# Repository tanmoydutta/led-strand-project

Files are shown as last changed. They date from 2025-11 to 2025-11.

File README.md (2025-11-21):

# Autonoe
An RGB and Neopixel LED controller board powered by ESP32-C3



The module has option for unified 5V supply for LEDs and the MCU LDO and can provide support for higher voltages via the dedicated barrel jack socket. Separate 5V power then can be supplied via the USB-C connector -


A small solder bridge unifies the circuit power for 5V power operations and for higher current feed via the barrel jack socket-


Dual LED interface for RGB and Addressable LEDs - 


This is an OSHWA certified hardware - 
<p align="center">
  <a href="https://certification.oshwa.org/nl000036.html">
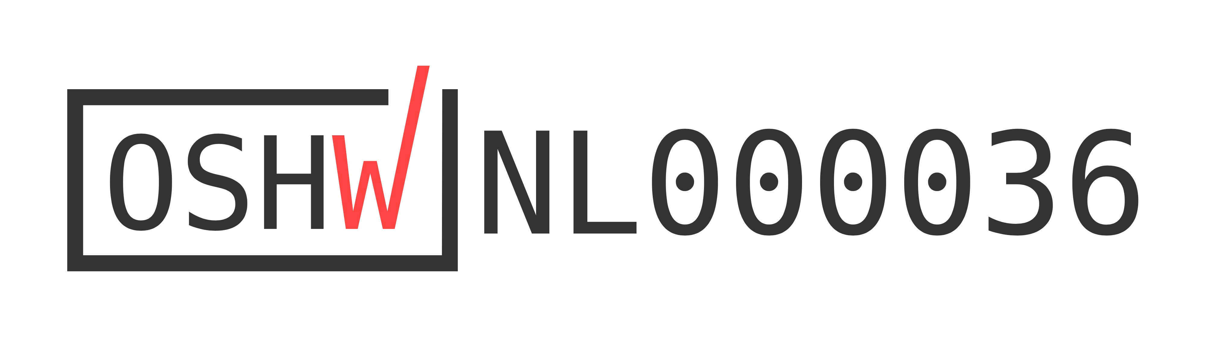
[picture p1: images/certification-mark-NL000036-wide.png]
OSHWA OSHWA Certification
    
  </a>
</p>



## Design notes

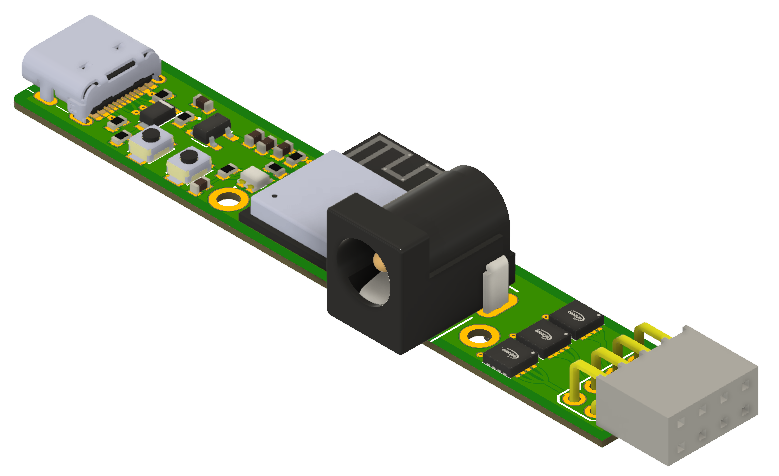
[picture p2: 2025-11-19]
images/AutonoeGingerBread3.png

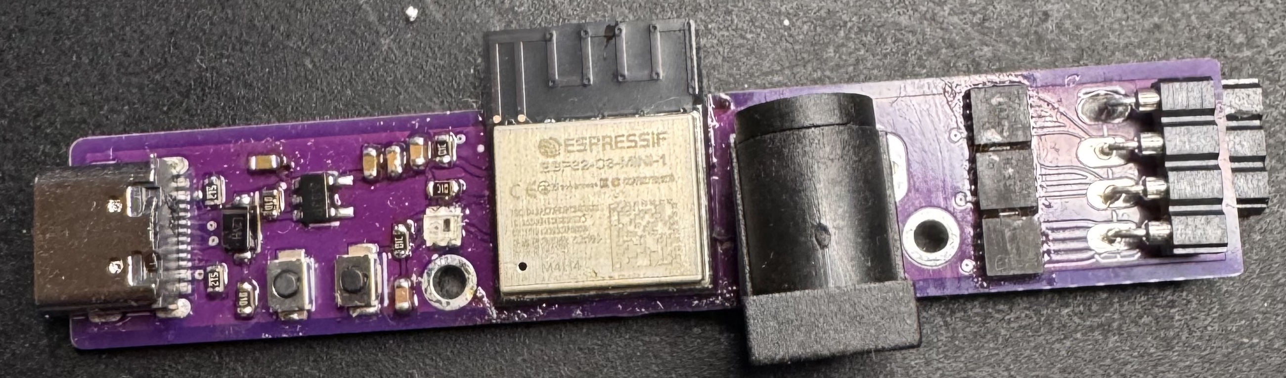
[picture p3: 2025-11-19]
images/module.jpg

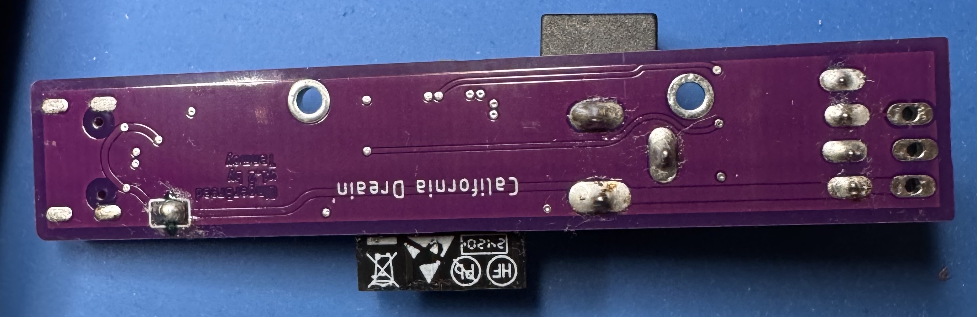
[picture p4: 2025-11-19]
images/module_back.jpg

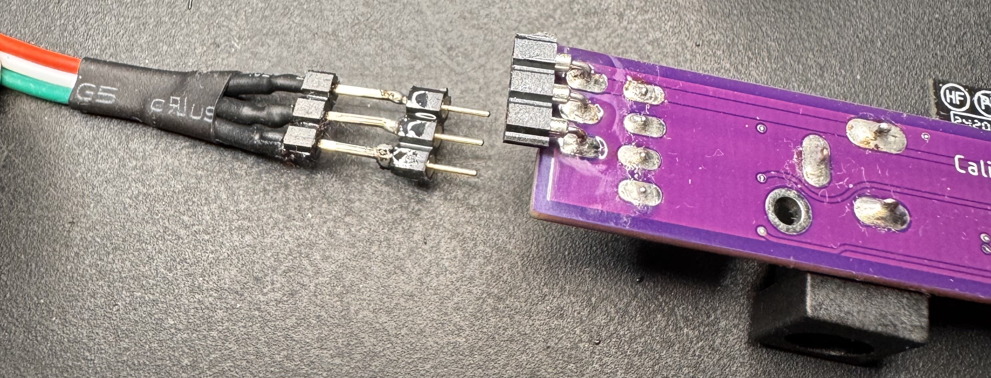
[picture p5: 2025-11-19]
images/addressable.jpg

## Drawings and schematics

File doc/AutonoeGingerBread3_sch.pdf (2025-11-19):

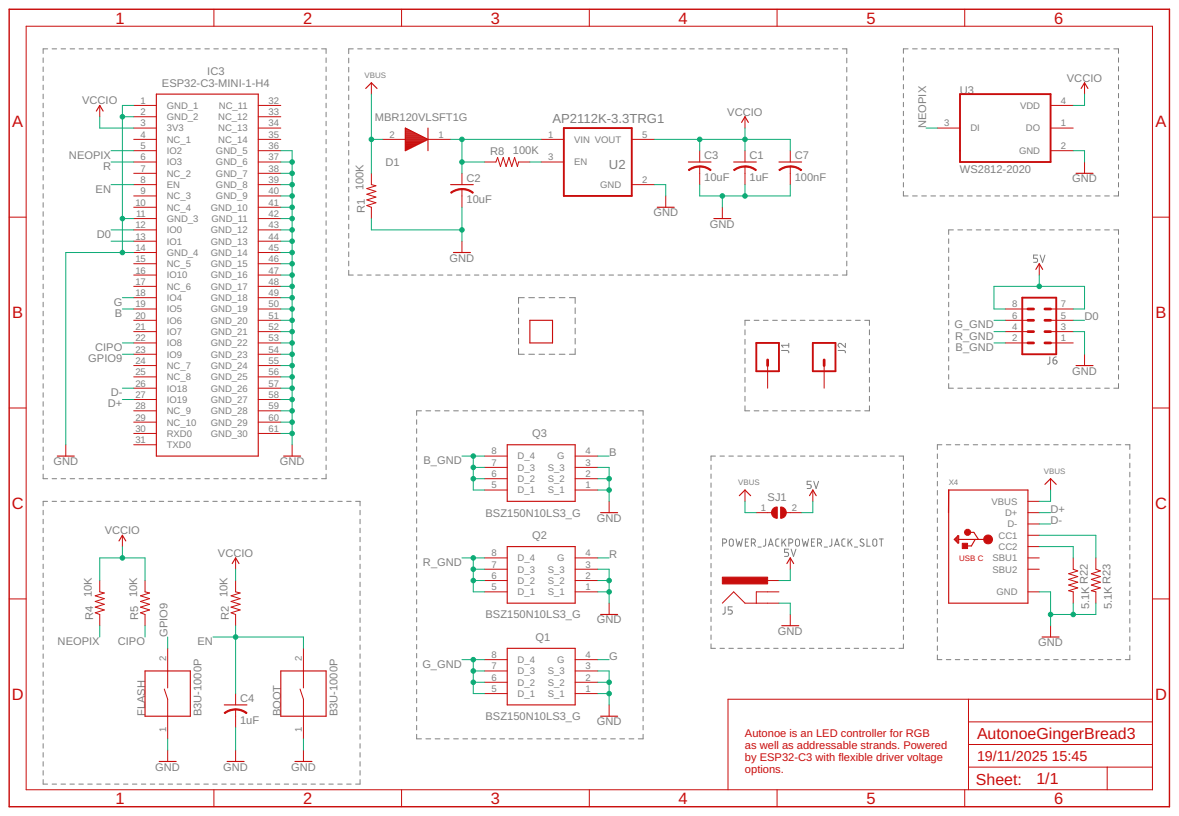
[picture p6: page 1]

44 GND_14 | GND

15 17 18 | | 46 GND_16

Autonoe is an LED controller for RGB as well as addressable strands. Powered by ESP32-C3 with flexible driver voltage options.

Sheet: 1/1

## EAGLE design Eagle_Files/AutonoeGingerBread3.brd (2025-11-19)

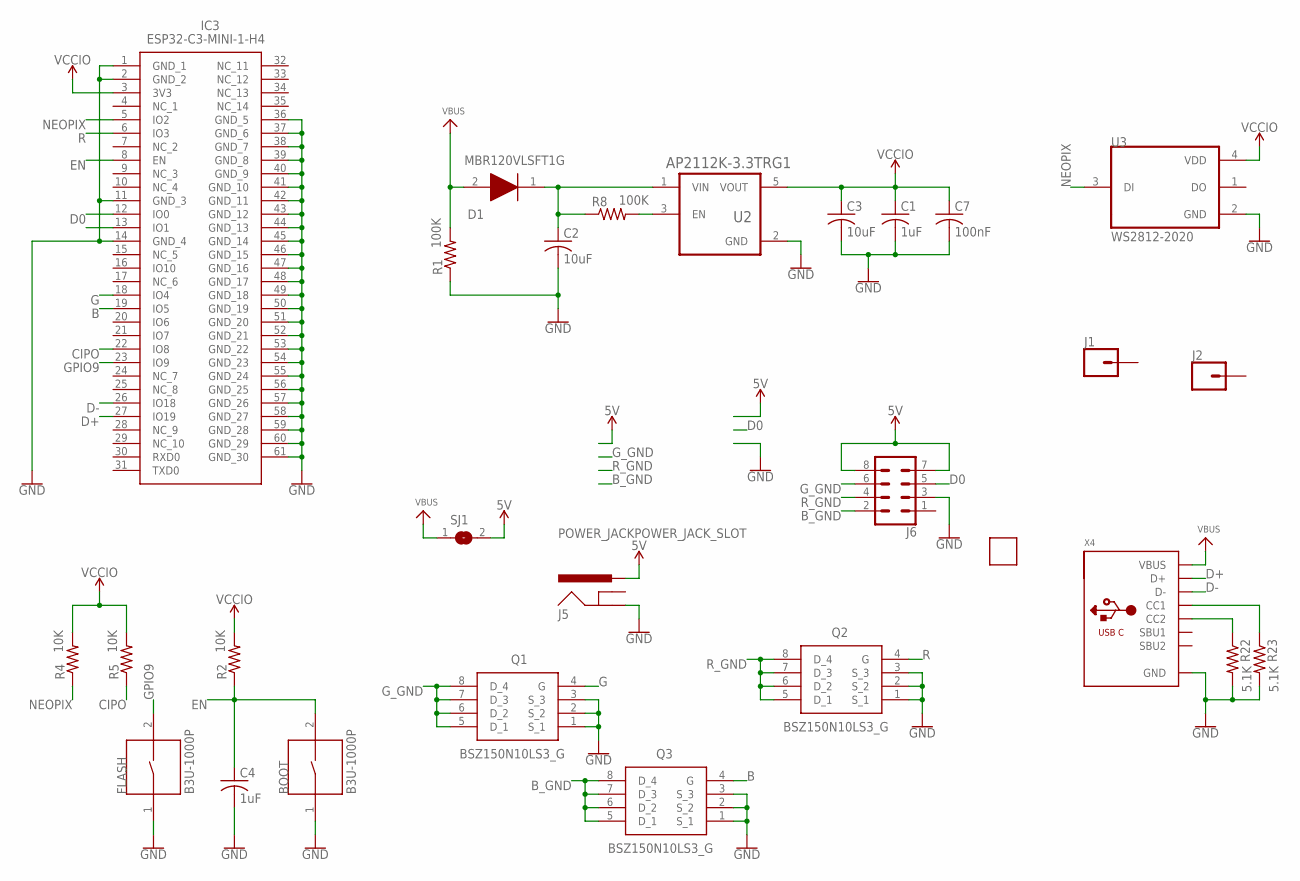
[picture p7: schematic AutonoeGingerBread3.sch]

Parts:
BOOT: B3U-1000P; SW_B3U-1000P
C1, C4: 1uF; C0402
C2, C3: 10uF; C0402
C7: 100nF; C0402
D1: MBR120VLSFT1G; SODFL3616X98N
FLASH: B3U-1000P; SW_B3U-1000P
IC3: ESP32-C3-MINI-1-H4; ESP32C3MINI1H4
J1, J2: CONN_01PTH_2MM; 1X01_2MM
J5: POWER_JACKPOWER_JACK_SLOT; POWER_JACK_PTH_SLOT
J6: CONN_04X2; 2X4
Q1, Q2, Q3: BSZ150N10LS3_G; BSZ180P03NS3EGATMA1
R1, R8: 100K; R0402
R2, R4, R5: 10K; R0402
R22, R23: 5.1K; R0402
SJ1: SJ
U2: AP2112K-3.3TRG1; SOT95P285X140-5N
U3: WS2812-2020; LED_WS2812-2020
U$3: SMARTT_SMALL
X4: MICROBUILDER_USB_C; MICROBUILDER_USB_C_CUSB31-CFM2AX-01-X

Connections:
5V: J5.PWR, J6.7, J6.8, SJ1.2
B: IC3.19 (IO5), Q3.4 (G)
B_GND: J6.2, Q3.5 (D_1), Q3.6 (D_2), Q3.7 (D_3), Q3.8 (D_4)
CIPO: IC3.22 (IO8), R5.1
D0: IC3.12 (IO0), J6.5
D+: IC3.27 (IO19), X4.A6 (D+), X4.B6 (D+)
D-: IC3.26 (IO18), X4.A7 (D-), X4.B7 (D-)
EN: BOOT.2, C4.1, IC3.8 (EN), R2.1
G: IC3.18 (IO4), Q1.4 (G)
GND: BOOT.1, C1.2, C2.2, C3.2, C4.2, C7.2, FLASH.1, IC3.1 (GND_1), IC3.2 (GND_2), IC3.11 (GND_3), IC3.14 (GND_4), IC3.36 (GND_5), IC3.37 (GND_6), IC3.38 (GND_7), IC3.39 (GND_8), IC3.40 (GND_9), IC3.41 (GND_10), IC3.42 (GND_11), IC3.43 (GND_12), IC3.44 (GND_13), IC3.45 (GND_14), IC3.46 (GND_15), IC3.47 (GND_16), IC3.48 (GND_17), IC3.49 (GND_18), IC3.50 (GND_19), IC3.51 (GND_20), IC3.52 (GND_21), IC3.53 (GND_22), IC3.54 (GND_23), IC3.55 (GND_24), IC3.56 (GND_25), IC3.57 (GND_26), IC3.58 (GND_27), IC3.59 (GND_28), IC3.60 (GND_29), IC3.61 (GND_30), J5.GND, J6.3, Q1.1 (S_1), Q1.2 (S_2), Q1.3 (S_3), Q2.1 (S_1), Q2.2 (S_2), Q2.3 (S_3), Q3.1 (S_1), Q3.2 (S_2), Q3.3 (S_3), R1.1, R22.2, R23.2, U2.2 (GND), U3.2 (GND), X4.A1B12 (GND), X4.B1A12 (GND)
GPIO9: FLASH.2, IC3.23 (IO9)
G_GND: J6.6, Q1.5 (D_1), Q1.6 (D_2), Q1.7 (D_3), Q1.8 (D_4)
unnamed: C2.1, D1.1 (K), R8.1, U2.1 (VIN)
unnamed: R22.1, X4.B5 (CC2)
unnamed: R23.1, X4.A5 (CC1)
unnamed: R8.2, U2.3 (EN)
NEOPIX: IC3.5 (IO2), R4.1, U3.3 (DI)
R: IC3.6 (IO3), Q2.4 (G)
R_GND: J6.4, Q2.5 (D_1), Q2.6 (D_2), Q2.7 (D_3), Q2.8 (D_4)
VBUS: D1.2 (A), R1.2, SJ1.1, X4.A4B9 (VBUS), X4.B4A9 (VBUS)
VCCIO: C1.1, C3.1, C7.1, IC3.3 (3V3), R2.2, R4.2, R5.2, U2.5 (VOUT), U3.4 (VDD)

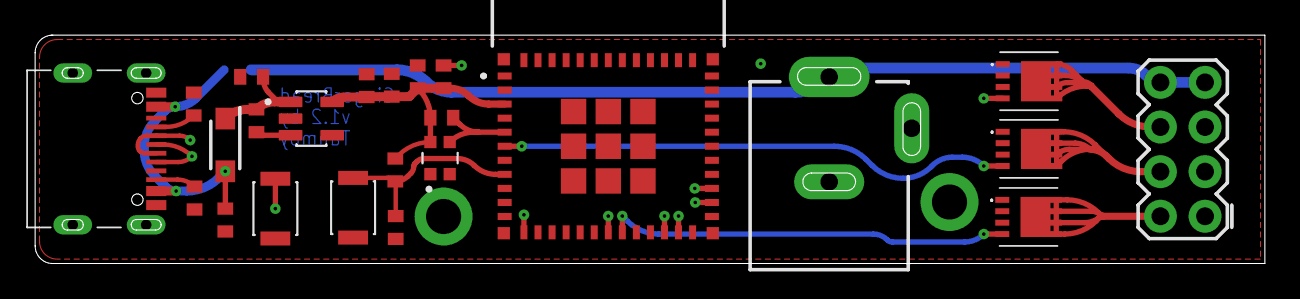
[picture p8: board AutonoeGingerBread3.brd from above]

Board: 4 copper layers, 70.0 x 13.0 mm, 28 parts (1 on the bottom side), 21 nets.

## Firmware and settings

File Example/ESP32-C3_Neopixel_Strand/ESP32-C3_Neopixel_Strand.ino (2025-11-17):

// A basic everyday NeoPixel strip test program.

// NEOPIXEL BEST PRACTICES for most reliable operation:
// - Add 1000 uF CAPACITOR between NeoPixel strip's + and - connections.
// - MINIMIZE WIRING LENGTH between microcontroller board and first pixel.
// - NeoPixel strip's DATA-IN should pass through a 300-500 OHM RESISTOR.
// - AVOID connecting NeoPixels on a LIVE CIRCUIT. If you must, ALWAYS
//   connect GROUND (-) first, then +, then data.
// - When using a 3.3V microcontroller with a 5V-powered NeoPixel strip,
//   a LOGIC-LEVEL CONVERTER on the data line is STRONGLY RECOMMENDED.
// (Skipping these may work OK on your workbench but can fail in the field)

#include <Adafruit_NeoPixel.h>
#ifdef __AVR__
 #include <avr/power.h> // Required for 16 MHz Adafruit Trinket
#endif

// Which pin on the Arduino is connected to the NeoPixels?
// On a Trinket or Gemma we suggest changing this to 1:
#define LED_PIN    0

// How many NeoPixels are attached to the Arduino?
#define LED_COUNT 15

// Declare our NeoPixel strip object:
Adafruit_NeoPixel strip(LED_COUNT, LED_PIN, NEO_GRB + NEO_KHZ800);
// Argument 1 = Number of pixels in NeoPixel strip
// Argument 2 = Arduino pin number (most are valid)
// Argument 3 = Pixel type flags, add together as needed:
//   NEO_KHZ800  800 KHz bitstream (most NeoPixel products w/WS2812 LEDs)
//   NEO_KHZ400  400 KHz (classic 'v1' (not v2) FLORA pixels, WS2811 drivers)
//   NEO_GRB     Pixels are wired for GRB bitstream (most NeoPixel products)
//   NEO_RGB     Pixels are wired for RGB bitstream (v1 FLORA pixels, not v2)
//   NEO_RGBW    Pixels are wired for RGBW bitstream (NeoPixel RGBW products)


// setup() function -- runs once at startup --------------------------------

void setup() {
  // These lines are specifically to support the Adafruit Trinket 5V 16 MHz.
  // Any other board, you can remove this part (but no harm leaving it):
#if defined(__AVR_ATtiny85__) && (F_CPU == 16000000)
  clock_prescale_set(clock_div_1);
#endif
  // END of Trinket-specific code.

  strip.begin();           // INITIALIZE NeoPixel strip object (REQUIRED)
  strip.show();            // Turn OFF all pixels ASAP
  strip.setBrightness(50); // Set BRIGHTNESS to about 1/5 (max = 255)
}


// loop() function -- runs repeatedly as long as board is on ---------------

void loop() {
  // Fill along the length of the strip in various colors...
  colorWipe(strip.Color(255,   0,   0), 50); // Red
  colorWipe(strip.Color(  0, 255,   0), 50); // Green
  colorWipe(strip.Color(  0,   0, 255), 50); // Blue

  // Do a theater marquee effect in various colors...
  theaterChase(strip.Color(127, 127, 127), 50); // White, half brightness
  theaterChase(strip.Color(127,   0,   0), 50); // Red, half brightness
  theaterChase(strip.Color(  0,   0, 127), 50); // Blue, half brightness

  rainbow(10);             // Flowing rainbow cycle along the whole strip
  theaterChaseRainbow(50); // Rainbow-enhanced theaterChase variant
}


// Some functions of our own for creating animated effects -----------------

// Fill strip pixels one after another with a color. Strip is NOT cleared
// first; anything there will be covered pixel by pixel. Pass in color
// (as a single 'packed' 32-bit value, which you can get by calling
// strip.Color(red, green, blue) as shown in the loop() function above),
// and a delay time (in milliseconds) between pixels.
void colorWipe(uint32_t color, int wait) {
  for(int i=0; i<strip.numPixels(); i++) { // For each pixel in strip...
    strip.setPixelColor(i, color);         //  Set pixel's color (in RAM)
    strip.show();                          //  Update strip to match
    delay(wait);                           //  Pause for a moment
  }
}

// Theater-marquee-style chasing lights. Pass in a color (32-bit value,
// a la strip.Color(r,g,b) as mentioned above), and a delay time (in ms)
// between frames.
void theaterChase(uint32_t color, int wait) {
  for(int a=0; a<10; a++) {  // Repeat 10 times...
    for(int b=0; b<3; b++) { //  'b' counts from 0 to 2...
      strip.clear();         //   Set all pixels in RAM to 0 (off)
      // 'c' counts up from 'b' to end of strip in steps of 3...
      for(int c=b; c<strip.numPixels(); c += 3) {
        strip.setPixelColor(c, color); // Set pixel 'c' to value 'color'
      }
      strip.show(); // Update strip with new contents
      delay(wait);  // Pause for a moment
    }
  }
}

// Rainbow cycle along whole strip. Pass delay time (in ms) between frames.
void rainbow(int wait) {
  // Hue of first pixel runs 5 complete loops through the color wheel.
  // Color wheel has a range of 65536 but it's OK if we roll over, so
  // just count from 0 to 5*65536. Adding 256 to firstPixelHue each time
  // means we'll make 5*65536/256 = 1280 passes through this loop:
  for(long firstPixelHue = 0; firstPixelHue < 5*65536; firstPixelHue += 256) {
    // strip.rainbow() can take a single argument (first pixel hue) or
    // optionally a few extras: number of rainbow repetitions (default 1),
    // saturation and value (brightness) (both 0-255, similar to the
    // ColorHSV() function, default 255), and a true/false flag for whether
    // to apply gamma correction to provide 'truer' colors (default true).
    strip.rainbow(firstPixelHue);
    // Above line is equivalent to:
    // strip.rainbow(firstPixelHue, 1, 255, 255, true);
    strip.show(); // Update strip with new contents
    delay(wait);  // Pause for a moment
  }
}

// Rainbow-enhanced theater marquee. Pass delay time (in ms) between frames.
void theaterChaseRainbow(int wait) {
  int firstPixelHue = 0;     // First pixel starts at red (hue 0)
  for(int a=0; a<30; a++) {  // Repeat 30 times...
    for(int b=0; b<3; b++) { //  'b' counts from 0 to 2...
      strip.clear();         //   Set all pixels in RAM to 0 (off)
      // 'c' counts up from 'b' to end of strip in increments of 3...
      for(int c=b; c<strip.numPixels(); c += 3) {
        // hue of pixel 'c' is offset by an amount to make one full
        // revolution of the color wheel (range 65536) along the length
        // of the strip (strip.numPixels() steps):
        int      hue   = firstPixelHue + c * 65536L / strip.numPixels();
        uint32_t color = strip.gamma32(strip.ColorHSV(hue)); // hue -> RGB
        strip.setPixelColor(c, color); // Set pixel 'c' to value 'color'
      }
      strip.show();                // Update strip with new contents
      delay(wait);                 // Pause for a moment
      firstPixelHue += 65536 / 90; // One cycle of color wheel over 90 frames
    }
  }
}

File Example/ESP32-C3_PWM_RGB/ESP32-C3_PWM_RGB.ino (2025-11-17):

#include <Arduino.h>

// Pin definitions
const int redPin   = 3;
const int greenPin = 4;
const int bluePin  = 5;

// PWM configuration
const uint32_t pwmFreq       = 5000;  // 5 kHz
const uint8_t  pwmResolution = 8;     // 8-bit (0-255)

// HSV→RGB conversion (for smooth fade)
void hsvToRgb(float h, float s, float v, uint8_t &r, uint8_t &g, uint8_t &b) {
  float c = v * s;
  float x = c * (1 - fabs(fmod(h / 60.0, 2) - 1));
  float m = v - c;
  float r1, g1, b1;

  if (h < 60)       { r1 = c; g1 = x; b1 = 0; }
  else if (h < 120) { r1 = x; g1 = c; b1 = 0; }
  else if (h < 180) { r1 = 0; g1 = c; b1 = x; }
  else if (h < 240) { r1 = 0; g1 = x; b1 = c; }
  else if (h < 300) { r1 = x; g1 = 0; b1 = c; }
  else              { r1 = c; g1 = 0; b1 = x; }

  r = (uint8_t)((r1 + m) * 255);
  g = (uint8_t)((g1 + m) * 255);
  b = (uint8_t)((b1 + m) * 255);
}

void setup() {
  Serial.begin(115200);
  while (!Serial) delay(10);
  Serial.println("ESP32-C3 RGB Fade (new LEDC API)");

  // Attach each pin to LEDC with new API
  if (!ledcAttach(redPin,   pwmFreq, pwmResolution))   Serial.println("Error attaching redPin");
  if (!ledcAttach(greenPin, pwmFreq, pwmResolution))   Serial.println("Error attaching greenPin");
  if (!ledcAttach(bluePin,  pwmFreq, pwmResolution))   Serial.println("Error attaching bluePin");
}

void loop() {
  static float hue = 0.0;
  uint8_t r, g, b;

  hsvToRgb(hue, 1.0, 1.0, r, g, b);

  // Write PWM duty via new API
  ledcWrite(redPin,   r);
  ledcWrite(greenPin, g);
  ledcWrite(bluePin,  b);

  hue += 1.0;
  if (hue >= 360.0) hue = 0.0;

  delay(15); // adjust to change fade speed
}

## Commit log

2025-11-19 Add and update documentation
    [AutonoeGingerBread3.brd, AutonoeGingerBread3.sch]
2025-11-19 Revise README for Autonoe LED controller project
    Updated project name and added detailed description with images.

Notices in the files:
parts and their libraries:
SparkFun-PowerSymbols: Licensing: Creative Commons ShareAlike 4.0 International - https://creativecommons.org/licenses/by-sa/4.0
